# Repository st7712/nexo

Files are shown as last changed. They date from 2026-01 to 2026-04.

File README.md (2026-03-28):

<div align="center">
  Nexo Logo
  <h1>Nexo Smart Speaker</h1>
  
  <p>
    <strong>A DIY, open-source smart speaker built on Raspberry Pi.</strong>
  </p>

  <p>
    <a href="https://github.com/st7712/nexo?tab=readme-ov-file#features">Features</a> •
    <a href="https://github.com/st7712/nexo?tab=readme-ov-file#installation">Installation</a> •
    <a href="https://github.com/st7712/nexo?tab=readme-ov-file#hardware">Hardware</a> •
    <a href="https://github.com/st7712/nexo?tab=readme-ov-file#configuration">Configuration</a> •
    <a href="https://discord.com/users/stitoo">Support</a>
  </p>

  
  
  
</div>

---

## About
**Nexo** converts a standard Raspberry Pi into a high-fidelity, network-aware smart speaker. Unlike standard Bluetooth speakers, Nexo acts as a central audio hub that intelligently manages input sources.

It runs a headless Python controller that seamlessly switches between **Spotify Connect** (High Quality WiFi streaming) and **Bluetooth** (for guests/offline use). It also features professional-grade DSP (Digital Signal Processing) via **Carla**, allowing for active crossover tuning, EQ, and room correction directly on the device.

<div align="center">
  Nexo speaker
</div>

## Features

- **Priority Audio Switching**: Automatically switches inputs. Playing Spotify pauses Bluetooth; stopping Spotify wakes Bluetooth back up.
- **Smart Connectivity**:
  - **Spotify Connect**: Stream directly from the cloud.
  - **Bluetooth 5.0**: High-quality A2DP sink with intelligent pairing.
- **Hardware Control**: Sonos-inspired play/pause/skip middle button, with side volume buttons, and status LEDs.
- **Pro-Audio Engine**: Uses [PipeWire](https://pipewire.org/) & [Carla](https://kx.studio/Applications:Carla) for low-latency audio processing and equalization.
- **API Controlled**: Built-in FastAPI backend for mobile app integration and smart home control.
- **Persistent Settings**: Remembers volume and EQ profiles across reboots.
- **Pretty good frequency response**: The exact speaker with the listed parts has a decent frequency response:
nexo curve
> Measured with an uncalibrated microphone with poor high frequency coverage and at 40 % speaker total volume.

## Installation

**Prerequisites:**
* Raspberry Pi 3B+, 4 or 5 (Recommended)
* Raspberry Pi OS (Bookworm or newer)

**Installer:**
SSH into your Raspberry Pi and run this command. It will install dependencies, compile Spotifyd, and configure system services automatically.

```bash
sudo apt update && sudo apt install -y git && \
git clone https://github.com/st7712/nexo.git && \
cd nexo && chmod +x install.sh && sudo ./install.sh
```

*Note: The installation may take 10-20 minutes depending on your Pi model (compiling Rust dependencies takes time).*

## Usage

### Physical Controls

| Button Input | Action |
| --- | --- |
| **Vol + / -** (Click for 5% / Hold for 10% continuous) | Changes Volume (Synchronized with Spotify/Bluetooth) |
| **Play (1 Click)** | Play / Pause |
| **Play (2 Clicks)** | Next Track |
| **Play (3 Clicks)** | Previous Track |
| **Play (Hold)** | **Force Pairing Mode / Restarts Spotify** (Disconnects current user from Bluetooth if Bluetooth active and also restarts Spotifyd) |

### API / App

The speaker hosts a local API at `http://<raspberry-pi-ip>:8000`. You can control playback, volume, EQ, and fetch metadata via REST.

## Hardware

Nexo is designed to work with generic I2S DACs (like HiFiBerry, Pimoroni, or generic PCM5102).

- **[View my Full Hardware Docs](https://github.com/st7712/nexo/blob/main/hardware/README.md)** 
- **[View my Bill of Materials (BOM)](https://github.com/st7712/nexo/blob/main/hardware/bom.md)**
- **[View my Full Hardware Assembly Guide](https://github.com/st7712/nexo/blob/main/hardware/assembly_guide.md)** 

## Configuration

Advanced users can tweak GPIO pins and audio settings.

1. **System Config**: Edit `assets/configs/nexo_config.json` (created after first run) or `DEFAULT_CONFIG ` in `src/data_handler.py` directly.
* Change `device_name` to whatever name you'd like
* Set `sounds` whether or not you want to have sound effects
* Modify `eq_presets` to change the equalizer presets to your liking
* Edit `max_volume` to match your specific amplifier
* ~Switch `master` if you'd like to have the specific speaker as just a listener, not a broadcaster~ (multi-room is in development)

2. **Pin Layout**: Edit `src/led_helper.py` if you use different GPIO pins for LEDs and `src/main.py` for buttons.
3. **Specific Carla settings**: Edit `src/carla_osc.py` if you somehow changed the Carla config and are using different plugins.

## Contributing

Contributions are welcome! Please open an issue or submit a pull request.

1. Fork the repo.
2. Create your feature branch (`git checkout -b feature/AmazingFeature`).
3. Commit your changes.
4. Push to the branch.
5. Open a Pull Request.

## Used Projects

* [Spotifyd](https://github.com/Spotifyd/spotifyd) - Lightweight Spotify Client
* [Carla](https://kx.studio/Applications:Carla) - Audio Plugin Host
* [FastAPI](https://fastapi.tiangolo.com/) - Modern Python Web Framework
* [Linux Studio Plugins](https://lsp-plug.in/) - VST Plugins Used In Carla

## Feedback

Created by **@stitoo**. Reach out on Discord or open a GitHub Issue!

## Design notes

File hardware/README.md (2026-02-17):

# Nexo Hardware Overview

This directory contains all the documentation regarding the physical construction, wiring, and component selection for the Nexo Smart Speaker.

Unlike standard 3D-printed speakers, Nexo aims for high-density acoustic properties by combining 3D printing, wood, and composite materials.

## Documentation

- **[Bill of Materials (BOM)](https://github.com/st7712/nexo/blob/main/hardware/bom.md)** - Full parts list, costs, and purchase links.
- **[Assembly Guide](https://github.com/st7712/nexo/blob/main/hardware/assembly_guide.md)** - Step-by-step tutorial on building the enclosure and wiring.

---

## Design Philosophy & Component Selection

### 1. The Subwoofer Enclosure (Plaster + PVA)

One of the biggest issues with DIY 3D printed speakers is that plastic is light and resonates easily, which makes the bass muddy.

- The subwoofer enclosure walls are designed with hollow cavities.
- I filled these cavities with a mixture of **Plaster of Paris**. Plaster of Paris and water is mixed using a 1:1 ratio, the **PVA glue** is then mixed with about an 1:10 ratio with the Plaster of Paris. I recommend trying out exact ratios yourself though.
- The PVA makes the plaster less brittle and significantly denser. This creates a "dead" cabinet that doesn't vibrate, resulting in much cleaner low-end frequencies.

### 2. The Amplifier (TPA3255)

I originally looked at standard TPA3116D2 boards, but settled on the **TPA3255 (SAMP-100)**.

- It has significantly cleaner power delivery, has **zero "thump" noise** when powering on or off. It also is very powerful and should handle pretty much anything. Lastly it was actually pretty cheap because I was purchasing it used.

### 3. The Brain (Raspberry Pi 5)

I used a Raspberry Pi 5 (4GB).

- **It's very overkill.** A Pi 3B+ or 4 would work fine. Any basic RPi that can run Linux will work.
- I wanted to get a powerful RPi that I will be able to use for my other personal usecases too, as well as future learning with microcontrollers. Another reason was the fact that the Pi 4 wasn't much cheaper than the 5, so I went for it.

---

## Challenges & Problems Encountered

### Ground loops

Originally, I planned to power everything from the single 36V Mean Well power supply, using a cheap DC-DC buck converter to step down 36V -> 5V for the Raspberry Pi.

This created a massive ground loop. The shared ground between the Amp and the Pi (via the buck converter) introduced audible whining and screeching noise into the audio signal. The music playback was unusable and you couldn't hear anything other than the loud screech.

I removed the buck converter entirely. The final build uses:

1.  **Mean Well 36V PSU** -> Powering ONLY the Amplifier.
2.  **Official Raspberry Pi PSU** -> Powering the Raspberry Pi.
    _This isolates the power grounds and results in a completely silent noise floor._

This also brings a benefit of being able to have the RPi running 24/7 without any coil whine, because the RPi PSU is silent.
However it does add another cable that goes to the speaker, which might make it look clunky.

If you prefer a single cable installation, I recommend getting either an isolated DC-DC converter, or an RCA (or AUX) ground loop isolator, which will effectively remove the ground loop, however the isolated DC-DC converter is expensive, and the RCA isolator might reduce audio quality.

Another internal PSU (like the RPi PSU) can be also actually placed inside of the enclosure and be wired up to the C14 connector, effectively using just one cable, however that would require more inside space, which I couldn't afford.

### Not ideal CAD design

There were a few issues when assembling the enclosure together.
The main issue was the lack of heat inserts or at least somewhat inserted screw nuts in the design, later requiring the manufacturing of special screw rings, that properly hold the speakers.

---

## 🖼️ Gallery

<div align="center">
  wiring diagram
  parts
</div>

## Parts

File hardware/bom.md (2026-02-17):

# Bill of Materials (BOM)

This is the list of parts used to build the reference version of the Nexo Speaker. Prices are estimates and may vary by region.

### Electronics

| Item | Description | Qty | Est. Cost | Notes | Link |
| :--- | :--- | :-- | :--- | :--- | --- |
| **Raspberry Pi 5 (4GB)** | The brain. Pi 4 also works. | 1 | $80 - $90 | Needs WiFi capability. I specifically chose this one as I'll use it for other projects too in the future. Such a powerful Pi isn't needed. | [Raspberry Pi](https://www.raspberrypi.com/products/raspberry-pi-5/) |
| **Raspberry Pi DAC+** | High-quality audio output board. | 1 | $25 | Any DAC will most likely work great. | [Raspberry Pi](https://www.raspberrypi.com/products/dac-plus/) |
| **Amplifier Board (TPA3255 SAMP-100)**  | Class D Amp, 2x315W. | 1 | $16 | Ensure it fits your power needs for your speakers. I specifically chose this one because it was for a good price and also because these TPA3255 boards do not have the thump noise when powering on/off that TPA3166D2 boards do have. | [Aliexpress](https://www.aliexpress.com/item/1005006169802448.html) |
| **Power Supply (Mean Well LRS-150-36)** | An industrial power supply | 1 | $24 | Powers the Amp and Raspberry Pi. You can choose any PSU you need, even an external one, I would personally not choose this exact one because of coil whine and tons of electrical noise going into the amp, however it's good enough. | Any official Mean Well store. |
| ~**DC-DC Buck Converter**~ | ~Steps down 36V -> 5V for the Pi.~ | ~1~ | ~$3~ | ~Choose one specifically for your Pi, I wanted a 5A one, because the Pi 5 wants 5A to be happy. This one delivers that and shouldn't fry the Pi.~ This was NOT used in the final version as it introduced a ground loop. I decided to get a secondary official Raspberry Pi PSU for the Pi 5. This does add another cable, but allows the Pi to run 24/7 with no noise. | ~[Aliexpress](https://www.aliexpress.com/item/1005009039465768.html)~ [Raspberry Pi](https://www.raspberrypi.com/products/27w-power-supply/) |
| **Buttons** | For Vol +/-, Play/Pause. | 3 | $1 each | I specifically chose ones that can sense a finger from a few milimeters away, because they'll be under the surface in the enclosure. | [Aliexpress](https://www.aliexpress.com/item/1005004477188195.html) |
| **White LEDs** | Status feedback. | 1 | $2 for 50-pack | I chose white color for a minimalistic look. | [Aliexpress](https://www.aliexpress.com/item/1005006885163813.html) |
| **PANASONIC AQY212EHAT opto-coupler** | For controlled AMP muting. | 1 | $3 | Because my AMP supports hardware muting when two pins are shorted, I am using an opto-coupler to control the short with the RPi. | Any local electronics store |

### Audio Components

| Item | Description | Qty | Est. Cost | Notes | Link |
| :--- | :--- | :--- | :--- | :--- | --- |
| **Woofer (4 inch)** | Mid-bass driver. | 1 | $25 | I chose the Dayton Audio TCP115-4 4", good little woofer for a good price. | [Amazon](https://www.amazon.com/Dayton-Audio-TCP115-4-Treated-Midbass/dp/B077FHPGM4) |
| **Tweeter (2 inch)** | Silk dome tweeters. | 1 (set of 2) | $7 | These tweeters are pretty decent for the price. | [Aliexpress](https://www.aliexpress.com/item/1005007917972560.html) |
| **Mid speakers (3 inch)** | Mid frequency speakers. | 1 (set of 2) | $11 | These are not all that great, but they get the job done. | [Aliexpress](https://www.aliexpress.com/item/1005007256226541.html) |
| **High-pass filter** | For tweeters. | 1 | $4 | You don't need it if you're not using tweeters. | [Aliexpress](https://www.aliexpress.com/item/1005001361438676.html) |

### Enclosure & Misc

| Item | Description | Notes |
| :--- | :--- | :--- |
| **PETG Filament** | About 1 kg of filament used + wood. | PCTG _might_ be better. |
| **Wooden board** | For the outer enclosure. | Makes it look neat and saves plastic. |
| **Plaster of paris mixture with PVA** | Acoustic stuffing for the woofer enclosure. | A classic 1:1 PoP mixture with a bit of added PVA to make it less brittle. |
| **Screws / Binding Posts** | For rigid links. | An y nice looking screws, I chose black DIN 7984. |
| **Various cables** | For all connections. | You should choose a cable thick enough to handle the power. I chose 14 AWG cables for power and 1.5qmm cables for speakers. |

**Total Estimated Cost:** ~$200 - $250 USD

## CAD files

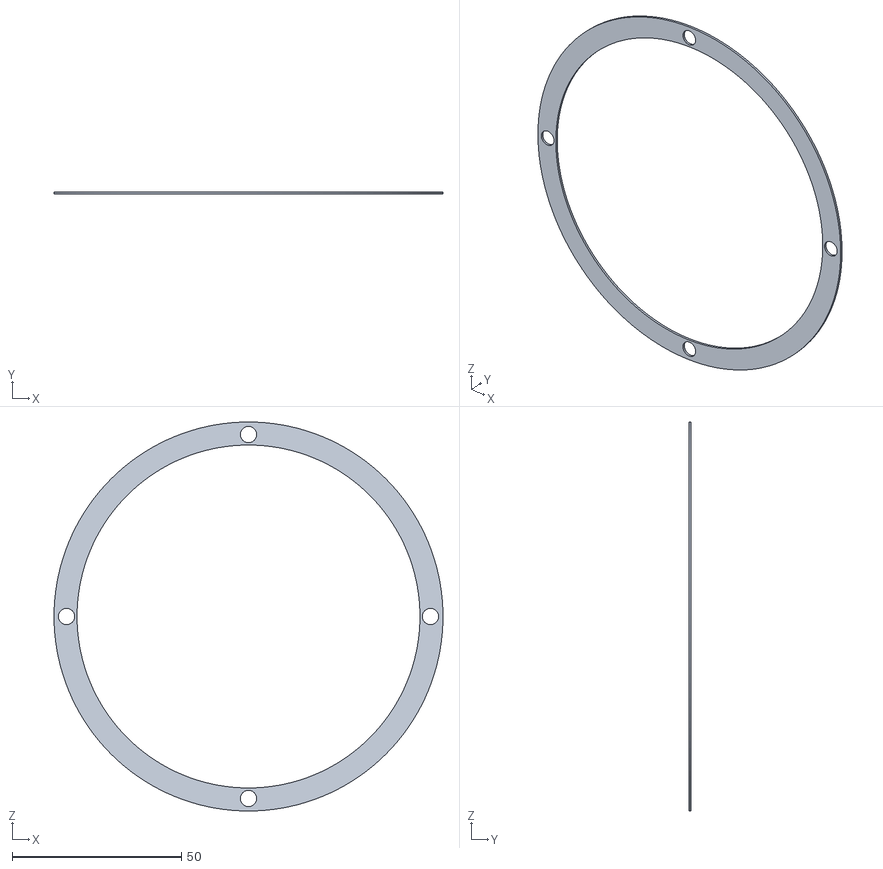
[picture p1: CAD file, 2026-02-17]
hardware/CAD/passive radiator rubber gasket.stl
114.8 x 0.7 x 114.8

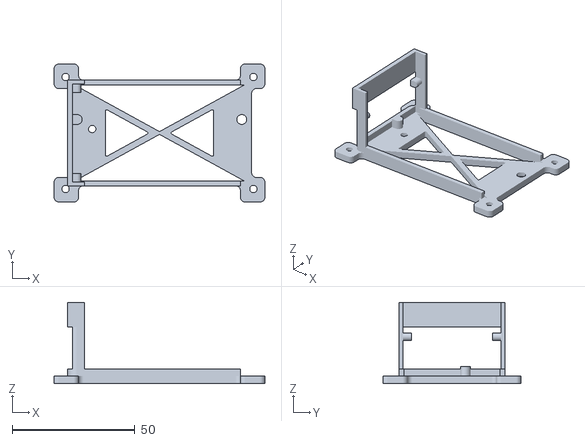
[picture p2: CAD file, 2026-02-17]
hardware/CAD/DC DC holder.stl
85.9 x 56.2 x 33.0

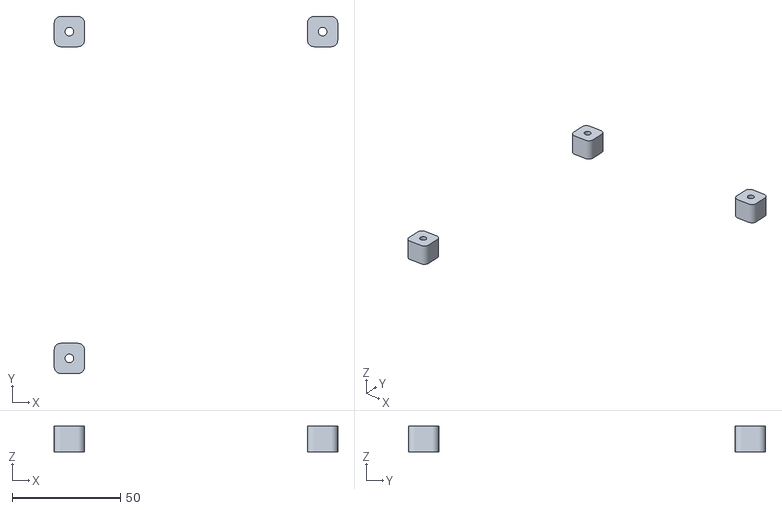
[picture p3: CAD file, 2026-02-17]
hardware/CAD/psu standoffs.stl
131.2 x 165.2 x 12.0

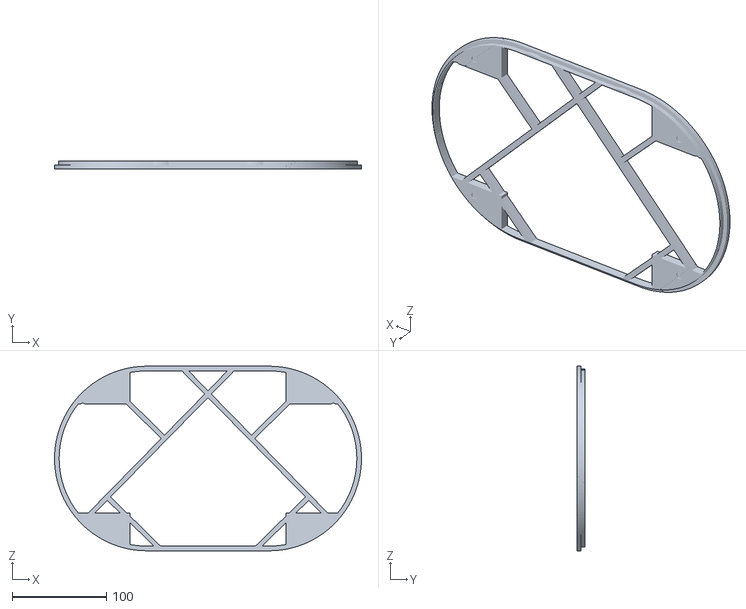
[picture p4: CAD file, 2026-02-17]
hardware/CAD/split front cover parts.stl
326.0 x 8.00 x 196.0

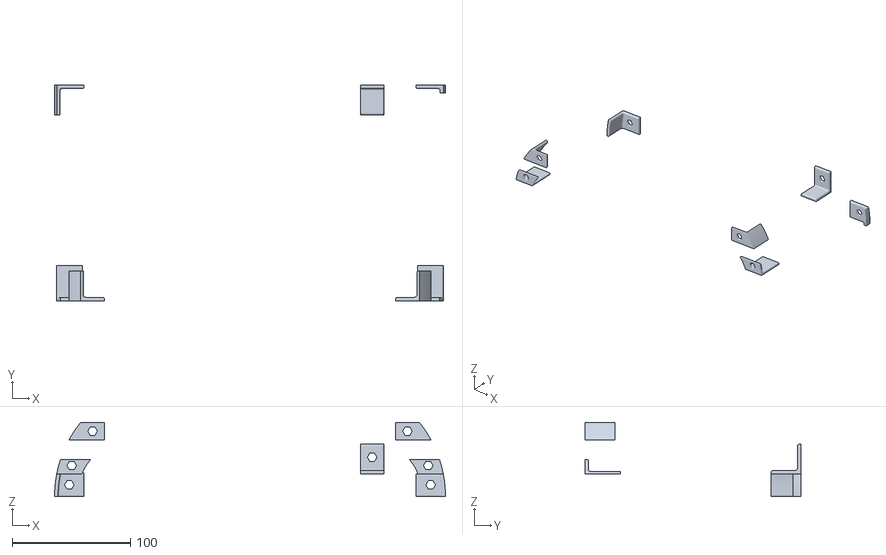
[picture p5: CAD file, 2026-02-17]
hardware/CAD/speaker enclosure holders.stl
330.0 x 182.0 x 62.8

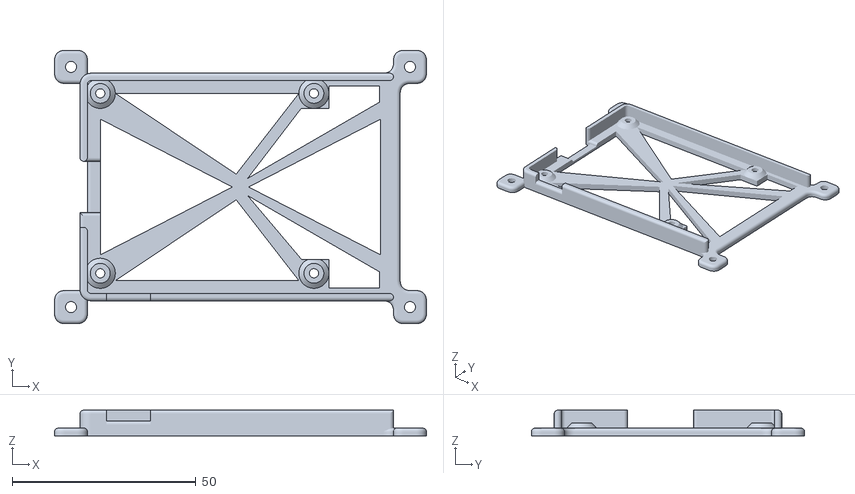
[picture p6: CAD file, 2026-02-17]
hardware/CAD/RPI5 holder.stl
101.3 x 74.4 x 7.00

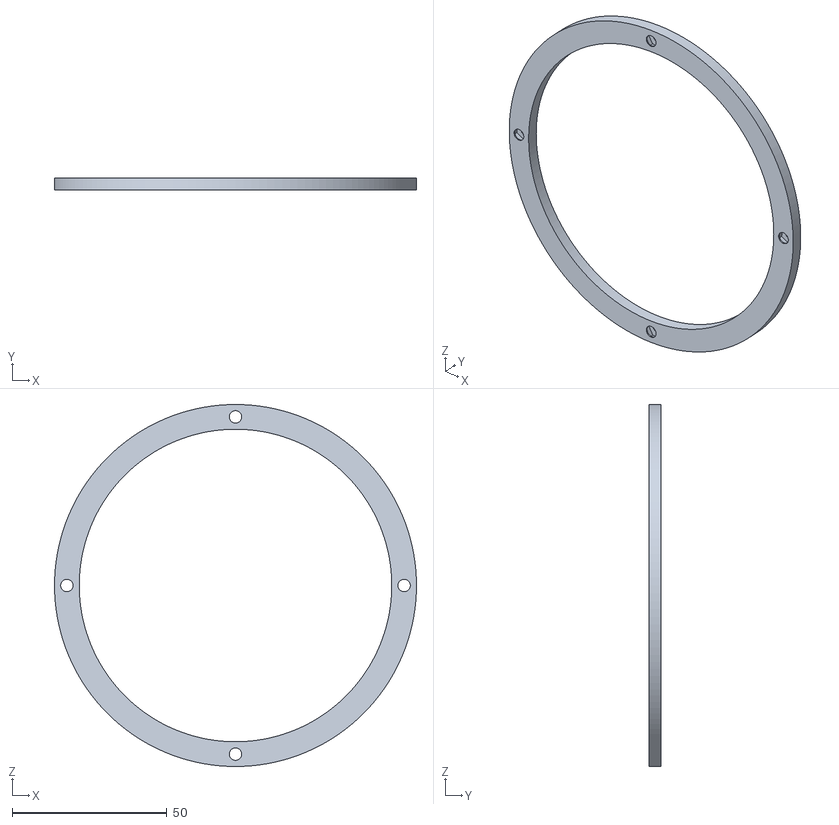
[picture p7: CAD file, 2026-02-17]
hardware/CAD/front speaker offset ring with nuts covered.stl
117.0 x 4.00 x 117.0

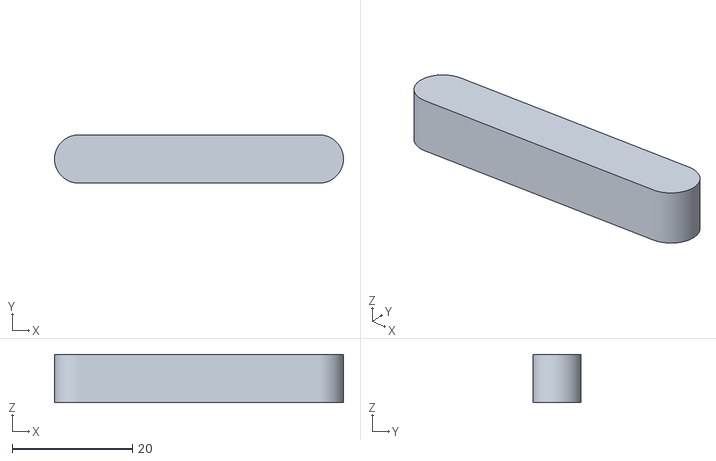
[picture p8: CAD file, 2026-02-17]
hardware/CAD/LED holder.stl
48.0 x 8.00 x 8.00

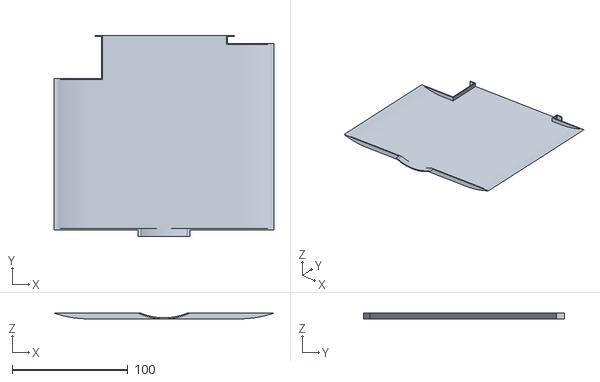
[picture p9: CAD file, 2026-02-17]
hardware/CAD/outside plaster enclosure top.stl
190.2 x 173.8 x 5.00

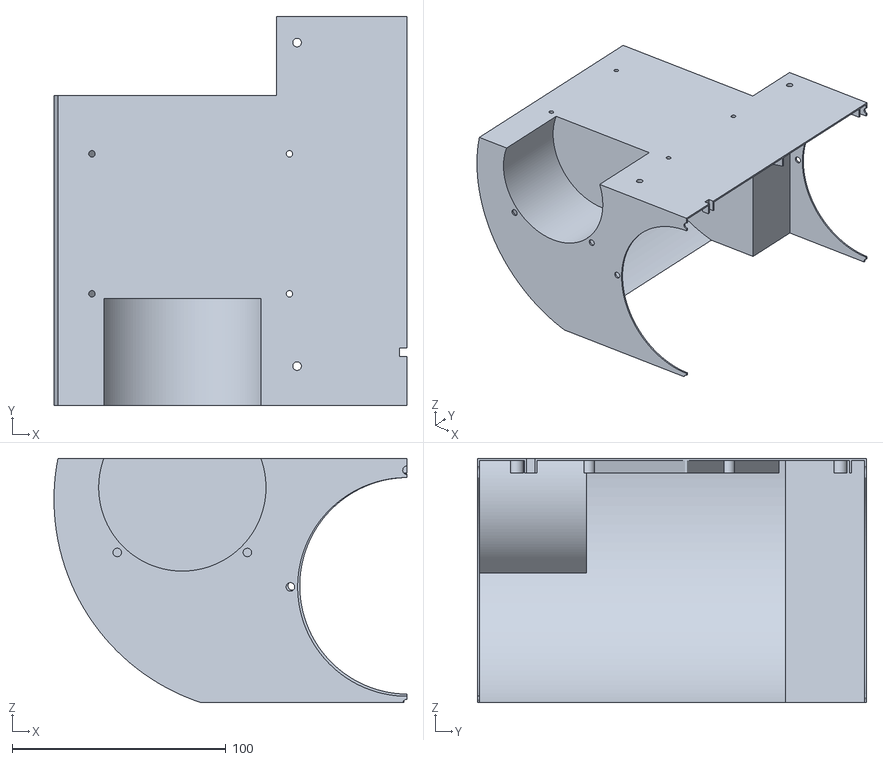
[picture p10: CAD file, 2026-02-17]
hardware/CAD/outside plaster enclosure 2.stl
165.0 x 182.0 x 114.2

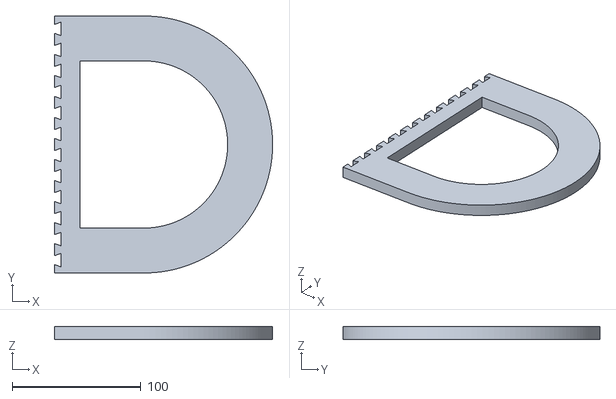
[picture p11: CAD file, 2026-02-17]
hardware/CAD/wood curve jig 2.stl
169.9 x 200.0 x 10.0

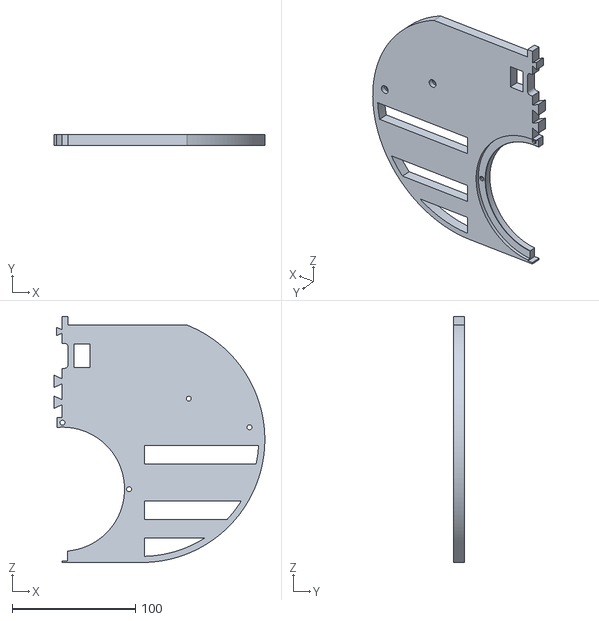
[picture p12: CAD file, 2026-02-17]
hardware/CAD/back plate 2.stl
171.3 x 9.00 x 200.0

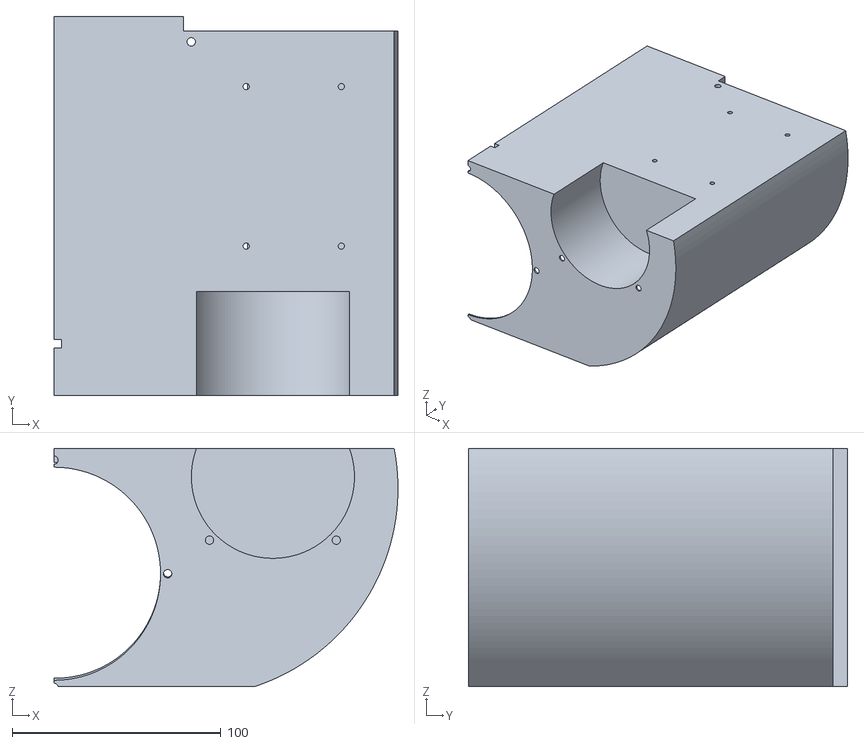
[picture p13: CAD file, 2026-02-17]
hardware/CAD/outside plaster enclosure 1.stl
165.0 x 182.0 x 114.2

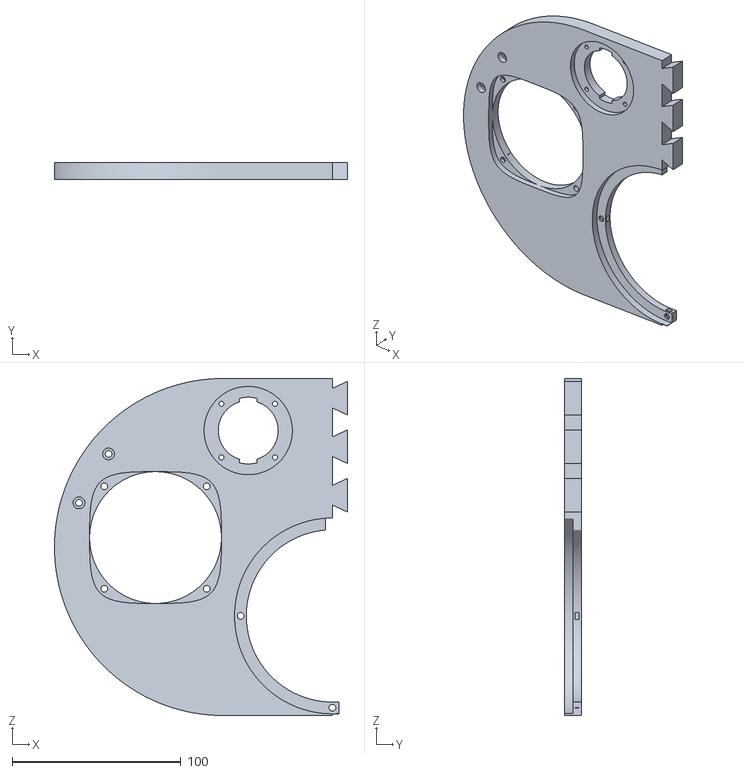
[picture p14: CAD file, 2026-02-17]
hardware/CAD/front plate 2.stl
174.0 x 10.0 x 200.0

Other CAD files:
hardware/CAD/PSU holder.stl
hardware/CAD/wood curve jig 1.stl
hardware/CAD/speaker bottom rubber v3.stl
hardware/CAD/inside plaster enclosure 1.stl
hardware/CAD/back plate 1.stl
hardware/CAD/front plate 1.stl
hardware/CAD/inside plaster enclosure 2.stl
hardware/CAD/inside plaster enclosure top.stl

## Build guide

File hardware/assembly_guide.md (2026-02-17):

# Nexo Assembly Guide

This guide details the process of printing, building, and wiring the Nexo Smart Speaker.

## Safety Warning

- **Mains Voltage:** This project uses an industrial power supply (110V/220V).
- **Chemicals:** When mixing Plaster and PVA, wear gloves and work in a ventilated area.
- **Wood working:** When cutting/sanding/milling the wooden parts, wear safety glasses and watch out for your hands.

---

## Phase 1: The Enclosure

### 1. 3D Printing

All parts were printed in **PETG** for durability and heat resistance.

- **Walls:** 2 perimeters (minimum).
- **Infill:** 15% Rectilinear (except for the subwoofer walls which are hollow for filling).

All printing parameters should be set to your specific printer. I personally printed everything on more filament and time saving settings and everything turned out great, so as long as you know which settings get you a decent quality print, I wouldn't be too worried about settings.

> **Note on Material:** PETG is completely fine to use, however using PCTG might be beneficial because of the higher temperature resistance (though in tests, it looks like it's not much different from PETG).

### 2. The Composite Fill (Subwoofer)

To give the subwoofer weight and acoustic density:

1.  Prepare a mixture of **90% Plaster of Paris** and **10% PVA Glue** (White wood glue).
2.  Add a small amount of water until it reaches a "pourable pancake batter" consistency if too viscous.
3.  Pour the mixture into the hollow cavities of the 3D-printed subwoofer shell.
4.  **Let it cure for at least 48 hours.** The PVA slows down the drying process but prevents the plaster from cracking. Also make sure it's in a well ventilated and/or heated area, so that it's not wet.
5.  Once it's all set, put some cotton wool (or polyfil) inside the enclosure, to help with bass response and make the enclosure feel "bigger" than it actually is.



### 3. Woodworking

The outer shell utilizes a wooden board for aesthetics and extra rigidity.

The wooden board uses a kerf bending method to bend the sides of the board according to the circular edges of the speaker enclosure. Make sure to cut the kerf cuts accordingly.

- Cut the board to size according to the following template including the kerf cuts.
- Use a router (or a Forstner bit) to carve out spaces for the buttons and LEDs.
- Sand up to 400 grit and apply oil/stain before final assembly.
- Bend (and glue the kerf cuts) the upper half of the board so that it fits the upper half of the speaker, leave the bottom straight so the speaker can be easily wrapped around with the wood.
- Finally varnish and color (if wanted) the wood enclosure to fit your needs.

This part can definitely also be 3D printed out of PETG, which was initially planned anyways. I just thought wood might look better plus it saved like 600 grams of plastic.



### Other Tasks

- Put a silicon ring around the holes for the subwoofer speaker and passive radiator to get a good seal on the enclosure. Caulk can be used for this.
- Glue everything needed together. (Such as the parts of the subwoofer enclosure, mounting rings to the enclosure).
- Paint and/or polish the look of the front and back plates. You can use wood filler to make it look more matte and less like plastic.
- Screw components into their specific holders.
- place the C14 plug and switch into its holes on the back plate, wire everything up.
- Screw the amplifier onto the inner side of the back plate and connect everything up correctly to it (the right channel to the woofer, the left channel to all the other speakers), the tweeters should be conneted through the high pass filter.

---

## Phase 2: Electronics & Wiring

### 1. Wiring Diagram

Below is a _(very professional)_ connection map of the Raspberry Pi and small electronics:

wiring diagram

- The LEDs and buttons are connected to a common ground coming from the RPi (the buttons connections depend on your specific buttons, mine required 5V, GND and had a signal OUT).
- Each LED is independently connected to the specific used pins to the RPi, every LED also has a resistor before connecting to the ground.
- Each button signal output is also connected to the RPi so that we know when it was pressed.
- Finally, the optocoupler is connected to its own pin and ground which then is able to control the muting of the amplifier using just a simple LOW/HIGH signal from the RPi.

### 2. Power System

- **Amp Power:** Connect the Mean Well 36V PSU output to the TPA3255 amp input using **14 AWG** silicone wire.
- **RPi Power:** Run the official USB-C power supply to the Pi 5.
  > Or you can power the RPi using the internal psu using an isolated DC-DC converter or by then using a ground loop isolator on the audio output of the RPi.

### 3. The Mute Circuit

Since the SAMP-100 TPA3255 amp board supports hardware muting, I implemented an optocoupler circuit to let the Pi mute the amp to prevent unnecessary electrical noise when no music is playing.

- **Optocoupler:** Panasonic AQY212EHAT.
- **Connection:**
  - _Input Side:_ GPIO 26 (RPi) -> Resistor -> Optocoupler LED -> GND (RPi).
  - _Output Side:_ Connects the Amp's MUTE and GND pins, polarity on this specific optocoupler and amp doesn't matter.

---

## Phase 3: Final Assembly

1.  **Mounting Drivers:** Screw the woofer and tweeters into the front plate.
2.  **Mounting Electronics:** Screw the electronic components in their mounting holders onto the enclosure.
3.  **Closing the Box:** Screw the subwoofer speaker and passive radiator very tightly into the subwoofer enclosure to ensure an airtight seal.
4.  **Wrap the rest using the bendable wood:** Enclose the whole speaker in the wood. Make sure the bottom part of the wooden board holds nicely, glue the bottom part down properly and let it sit for a while.

The whole speaker should be finished now.

---

## What I would do differently

Here are things I would change in a future build. You might want to consider these before you build yours:

### 1. Threaded Inserts

In this version, I screwed directly into the plastic and/or used nuts held in place by friction and super glue.

- Use **Heat-Set Inserts (M3/M4)** for every screw point. Redesign the 3D files to accommodate them.
- This will overall fix mounting issues and might help seal the subwoofer enclosure airtight a bit more.

### 2. Power Supply Integration

Having two power plugs (one for Amp, one for Pi) is clunky.

- Find an isolated DC-DC converter that actually works without ground loops, or build a custom linear power supply stage to feed 5V from the 36V rail cleanly.
  > Or just use a ground loop isolator at the RCA DAC connections (might hurt audio quality).

### 3. Ease of opening

Currently, removing the wooden is practically impossible, because it's glued down to the actual speaker enclosure.

- It would be a lot better to make some mounting plates sticking out of the wood to properly mount the back and front plates, so that it can be removed properly.
- Also placing all of the back plate mounted components onto the enclosure might help too, because the back plate would be removable a bit better, however it still has all the mains power on it, which is still a big issue.

> These are all quality of life improvements, that physically don't need to be there for it to work really good, but they could be good to have in the long term. For me though, they don't really cause issues for now.

---

## All .stl files for 3D printing are available in the `/files` directory.

- All CAD was designed in OnShape and the direct link to the CAD so you can clone it and edit parts directly is [**here**](https://cad.onshape.com/documents/64120ed53810ec4d5c769f33/w/fbffd58ca4d500f12472e03c/e/86b9a890bc291adbebea1ccb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)

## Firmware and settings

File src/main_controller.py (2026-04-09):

from threading import Timer, Thread
from time import sleep
import subprocess

import spotify_helper as spotify
import led_helper as leds
import bluetooth_helper as bluetooth
import system_helper as system
import data_handler
from carla_osc import set_loudness_contour_eq

# --- SHARED STATE ---
# This dictionary lives here. Anyone importing this file shares this state
# (as long as they run in the same process).
state = {
    'volume': data_handler.db.get("volume", 50),
    'max_volume': data_handler.db.get("max_volume", 50),
    'current_mode': 'spotify', # 'spotify' or 'bluetooth'
    'bt_owner_mac': None,
    'click_count': 0,
    'click_timer': None,
    'down_held': False,
    'up_held': False,
    'active_btn': None,
}

LOUDNESS_SLOPES = {
    40: 0.00394,
    63: 0.00521,
    100: 0.00372,
}

CONNECT_SOUND_PATH = f"{data_handler.db.get('root_path')}/assets/sounds/connect.wav"

# volume functions
def sync_volume():
    """Syncs internal state with Spotify's actual volume."""
    state['volume'] = spotify.get_volume()
    print(f"Synced volume: {state['volume']}%")

def change_volume(amount, override=False):
    """
    Main volume function. Called by Buttons OR API.
    """
    old_volume = state['volume']
    
    # Update State
    if override:
        new_volume = max(0, min(100, amount))
    else:
        new_volume = max(0, min(100, state['volume'] + amount))
        
    state['volume'] = new_volume
    
    if new_volume > old_volume:
        # Drop EQ first to prevent clipping
        update_loudness_contour(new_volume)
        _apply_hardware_volume(new_volume)
    elif new_volume < old_volume:
        # Drop Amp volume first to prevent bass spikes
        _apply_hardware_volume(new_volume)
        sleep(2) # Short delay to let hardware catch up before adjusting EQ
        update_loudness_contour(new_volume)

    # Visual Feedback and save to DB
    leds.update_volume_display(state['volume'])
    data_handler.db.set("volume", state['volume'])

def _apply_hardware_volume(vol):
    """Helper function to apply volume changes to the correct output."""
    if state['current_mode'] == 'bluetooth':
        bluetooth.set_bluetooth_volume(vol)
        print(f"Vol (BT): {vol}")
    else:
        spotify.set_volume(vol)
        print(f"Vol (Spotify): {vol}")

def get_volume():
    sync_volume() # Ensure we have the latest volume before returning
    return state['volume']

# media control functions
def media_action(action):
    """
    Unified media control.
    action: 'play_pause', 'next', 'prev', 'kick_spotify', 'pairing_mode'
    """
    print(f"Controller: Executing {action}")
    
    if action == 'play_pause':
        spotify.play_pause()
        leds.ramp_main_led(0.1)
        update_mute_status() # Check immediately
        
    elif action == 'next':
        spotify.next_track()
        leds.ramp_main_led(0.1)
        sleep(0.1)
        leds.ramp_main_led(0.1)
        
    elif action == 'prev':
        spotify.previous_track()
        leds.ramp_main_led(0.1)
        sleep(0.1)
        leds.ramp_main_led(0.1)
        sleep(0.1)
        leds.ramp_main_led(0.1)

    elif action == 'kick_spotify':
        # Force Restart Spotifyd
        leds.ramp_main_led(0.1)
        sleep(0.1)
        leds.ramp_main_led(0.1)
        system.restart_spotifyd()
        
    elif action == 'pairing_mode':
        # Force Bluetooth Pairing
        leds.ramp_main_led(1.0) # Long flash
        state['bt_owner_mac'] = None
        system.enter_pairing_mode()
        # Flash to indicate searching
        for _ in range(5):
            leds.ramp_main_led(0.1)
            sleep(0.1)

# background workers
def update_mute_status(status=None):
    """Checks if we should mute the Amp."""
    print(f"Updating Amp Mute Status...{status}")
    try:
        if status is None:
            status = subprocess.check_output(["playerctl", "status"], text=True).strip()
        if status == "Playing":
            leds.set_amp_mute(False)
        else:
            leds.set_amp_mute(True)
    except:
        leds.set_amp_mute(True)

global status

def background_worker_loop():
    """
    The main brain loop. Checks priority, muting, and bluetooth security.
    """
    hardware_sink = system.find_hardware_sink()
    
    while True:
        # Check Spotify Status
        spotify_active, status = system.is_spotify_active()
        
        if (not status):
            status = "unknown"
        
        # Handle Amp Mute
        # To save another request to the terminal, we pass the status we already have
        update_mute_status(status)
        
        # If paused, start a timer to kick after 5 minutes
        if spotify_active and status == "Paused" and 'spotify_disconnect_timer' not in globals():
            print("Spotify is paused. Starting disconnect timer.")
            
            global spotify_disconnect_timer
            
            spotify_disconnect_timer = Timer(300, media_action, args=('kick_spotify',))
            
            spotify_disconnect_timer.start()
        elif status != "Paused" and 'spotify_disconnect_timer' in globals():
            # Cancel any existing timer
            try:
                print("Cancelling disconnect timer.")
                spotify_disconnect_timer.cancel()
                del spotify_disconnect_timer
            except Exception:
                pass

        # Priority Switching
        # Spotify just started playing -> Kill BT
        if spotify_active and state['current_mode'] == 'bluetooth':
            print(">>> Priority: Spotify took over.")
            system.turn_off_bluetooth()
            state['current_mode'] = 'spotify'
            system.play_sound(CONNECT_SOUND_PATH, volume=(get_volume() * 300))  # Scale 0-100 to 0-65536
            leds.ramp_main_led(1.0) # Feedback

        # Spotify stopped -> Restore BT
        elif not spotify_active and state['current_mode'] == 'spotify':
            print(">>> Priority: Spotify gone. Restoring BT.")
            system.turn_on_bluetooth()
            state['current_mode'] = 'bluetooth'
            state['bt_owner_mac'] = None # Open for connections
            leds.ramp_main_led(1.0) # Feedback

        # Bluetooth Security
        if state['current_mode'] == 'bluetooth':
            _bluetooth_bouncer()

        system.set_hardware_volume(state['max_volume'], forced_sink=hardware_sink)

        sleep(2)

def _bluetooth_bouncer():
    """Ensures only 1 person connects and trusts them."""
    try:
        connected = bluetooth.get_connected_devices()

        # New Connection -> Lock it
        if state['bt_owner_mac'] is None and len(connected) > 0:
            state['bt_owner_mac'] = connected[0]
            print(f"BT Locked to: {state['bt_owner_mac']}")

            # Make invisible so nobody else tries to pair
            subprocess.run(["bluetoothctl", "discoverable", "off"], check=False)
            subprocess.run(["bluetoothctl", "pairable", "off"], check=False)

        # Owner Left -> Unlock
        elif state['bt_owner_mac'] and state['bt_owner_mac'] not in connected:
            state['bt_owner_mac'] = None
            print("BT Unlocked.")
            
            # Re-open the doors for anyone
            subprocess.run(["bluetoothctl", "discoverable", "on"], check=False)
            subprocess.run(["bluetoothctl", "pairable", "on"], check=False)

        # Intruder -> Kick
        if len(connected) > 1:
            print(f"Too many devices! Enforcing limit...")
            for mac in connected:
                if mac != state['bt_owner_mac']:
                    bluetooth.disconnect_device(mac)
                    
    except Exception as e:
        print(f"Enforcer Error: {e}")

def volume_worker_loop():
    """Polls playerctl at 10Hz to catch external volume changes instantly."""
    
    last_known_volume = get_volume()
    
    while True:
        try:
            result = subprocess.run(
                ["playerctl", "volume"], 
                capture_output=True, 
                text=True, 
                timeout=0.2
            )
            if result.returncode == 0 and result.stdout.strip():
                external_vol_float = float(result.stdout.strip())
                current_vol = int(external_vol_float * 100)
                
                if current_vol != last_known_volume:
                    state['volume'] = current_vol
                    update_loudness_contour(current_vol)
                    
                    leds.update_volume_display(current_vol)
                    data_handler.db.set("volume", current_vol)
                    
                    last_known_volume = current_vol
                    
        except subprocess.TimeoutExpired:
            pass # DBus was busy, just try again next loop
        except ValueError:
            pass # playerctl returned something weird (not a number)
        except Exception as e:
            # playerctl might return an error if no players are active. Just ignore.
            pass
            
        sleep(0.1)

def start_workers():
    t = Thread(target=background_worker_loop, daemon=True)
    t.start()
    
    v = Thread(target=volume_worker_loop, daemon=True)
    v.start()

def get_full_system_state():
    """
    Compiles the complete state of the speaker for the App.
    """
    sync_volume()  # Ensure volume is up to date
    # Get Playback Data
    if state['current_mode'] == 'spotify':
        track_data = spotify.get_track_info()
    else:
        track_data = system.get_track_info_bluetooth()

    # Combine with System State
    full_state = {
        "volume": get_volume(),
        "mode": state['current_mode'],
        "track": track_data,
    }

    return full_state

def get_partial_system_state():
    """
    Returns a minimal state for quick checks.
    """
    sync_volume()  # Ensure volume is up to date
    partial_state = {
        "volume": get_volume(),
        "status": system.is_spotify_active()[1],
        "position": spotify.get_track_position(),
    }
    return partial_state

# system functions

def scan_wifi_networks():
    """Scans for available WiFi networks and returns a list of SSIDs."""
    networks = system.scan_wifi_networks()
    return networks

def connect_to_wifi(ssid, password):
    """Connects to a specified WiFi network."""
    system.connect_to_wifi(ssid, password)
    
def pairing_mode():
    """Enters speaker pairing mode."""
    system.create_temp_hotspot()
    
def update_loudness_contour(current_volume):
    """Updates the Loudness Contour EQ settings."""
    vol_drop = 80 - current_volume # Calculate how much the volume is reduced from max
    
    eq_settings = {}
    
    for freq, slope in LOUDNESS_SLOPES.items():
        osc_val = 0.5 + (slope * vol_drop) # Start at 0.5 (flat) and adjust based on volume drop
        osc_val = max(0.5, min(1.0, osc_val)) # Clamp between 0.5 and 1
        eq_settings[int(freq)] = round(osc_val, 3) # Round for cleaner OSC messages
        
    set_loudness_contour_eq(eq_settings)
    
    print(f"Loudness Contour Updated: {eq_settings}")

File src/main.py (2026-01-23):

from gpiozero import Button
from signal import pause
from time import sleep
from threading import Timer, Thread
import uvicorn

import main_controller as controller
import led_helper as leds
import startup
from data_handler import db
from api import app

# Pins
BTN_VOL_DOWN = 13
BTN_PLAY = 6
BTN_VOL_UP = 5

# Settings
HOLD_TIME = 0.6 # Faster hold response
BOUNCE_TIME = 0.05
MULTI_CLICK_SPEED = 0.4 
RAMP_SPEED = 0.1

# Buttons
btn_down = Button(BTN_VOL_DOWN, pull_up=False, hold_time=HOLD_TIME, bounce_time=BOUNCE_TIME)
btn_play = Button(BTN_PLAY, pull_up=False, hold_time=2.0, bounce_time=BOUNCE_TIME)
btn_up = Button(BTN_VOL_UP, pull_up=False, hold_time=HOLD_TIME, bounce_time=BOUNCE_TIME)

# Button handlers

# Volume
def on_vol_held(direction):
    """
    direction: 1 (Up) or -1 (Down)
    """
    button_name = "UP" if direction > 0 else "DOWN"
    print(f"Holding {button_name}")
    
    # Identify which button object to check
    btn_obj = btn_up if direction > 0 else btn_down
    
    controller.state['active_btn'] = button_name
    
    if direction > 0:
        controller.state['up_held'] = True
    else:
        controller.state['down_held'] = True
    
    if controller.state['active_btn'] != button_name:
        return # Another button took over

    controller.sync_volume()
    
    # Loop while user holds the button
    while btn_obj.is_pressed:
        if controller.state['active_btn'] != button_name:
            return # Another button took over
        controller.change_volume(5 * direction) # Change by +/- 5
        leds.ramp_main_led() # Tiny blink for feedback
        sleep(RAMP_SPEED)

def on_vol_press(direction):
    button_name = "UP" if direction > 0 else "DOWN"
    
    controller.state['active_btn'] = button_name
    
    if direction > 0 and controller.state['up_held']:
        controller.state['up_held'] = False
        return # Ignore, was part of hold
    elif direction < 0 and controller.state['down_held']:
        controller.state['down_held'] = False
        return # Ignore, was part of hold
    
    if controller.state['active_btn'] != button_name:
        return # Another button took over
    
    print(f"Tap {button_name}")
    controller.sync_volume()
    controller.change_volume(5 * direction)
    leds.ramp_main_led() # Tiny blink for feedback

# Play button
def execute_play_logic():
    count = controller.state['click_count']
    controller.state['click_count'] = 0 # Reset
    
    if count == 1:
        controller.media_action('play_pause')
    elif count == 2:
        controller.media_action('next')
    elif count >= 3:
        controller.media_action('prev')

def on_play_press():
    # Cancel previous timer
    if controller.state['click_timer']:
        controller.state['click_timer'].cancel()
    
    controller.state['click_count'] += 1
    
    # Start new timer
    t = Timer(MULTI_CLICK_SPEED, execute_play_logic)
    controller.state['click_timer'] = t
    t.start()

def on_play_hold():
    # Long press determines action based on current mode
    if controller.state['current_mode'] == 'spotify':
        controller.media_action('kick_spotify')
    else:
        controller.media_action('pairing_mode')
        sleep(0.5)
        controller.media_action('kick_spotify')

# Bindings

def start_api_server():
    # We run uvicorn programmatically.
    uvicorn.run(app, host="0.0.0.0", port=8000, log_level="warning")

# Volume Up
btn_up.when_released = lambda: on_vol_press(1)
btn_up.when_held = lambda: on_vol_held(1)

# Volume Down
btn_down.when_released = lambda: on_vol_press(-1)
btn_down.when_held = lambda: on_vol_held(-1)

# Play
btn_play.when_pressed = on_play_press
btn_play.when_held = on_play_hold

# Startup Sequence
sleep(3) # Wait for system to settle
print("--- BOOTING NEXO SPEAKER ---")
leds.set_amp_mute(True) # Mute Amp during startup
print(db.get("volume"))

print("--- DEBUG CONFIG ---")
print(db.get_all())
# Run System Startup (Carla, Spotifyd)
startup.start_up(db.get("volume", 50), db.get("max_volume", 50))

# Sync Initial Volume
controller.sync_volume()

# Start Background Workers (Priority, Mute, Bluetooth)
controller.start_workers()

# Start API Server Thread
# We start this in a daemon thread so it runs in the background
api_thread = Thread(target=start_api_server, daemon=True)
api_thread.start()
print("--- API SERVER STARTED (Port 8000) ---")

print("--- SYSTEM READY ---")

if db.get("wifi")["ssid"] == "":
    print("No WiFi configured. Entering pairing mode.")
    controller.pairing_mode()

pause()

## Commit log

2026-01-16 made play_sound function have a dynamic volume based on current speaker volume
2026-01-16 edited data_handler to handle dynamic root path resolving for stability, added max_volume setting
    [data_handler.py]
2026-01-17 added default sink set to PulseAudio virtual cable device to startup sequence
2026-01-23 changed equalizer base values to a more calibrated curve for my speaker
2026-01-23 updated max_volume of my specific speaker to 55, made everything else resolve to 50.
    [data_handler.py, main.py, main_controller.py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]
2026-02-17 Update assembly guide with images
2026-02-17 added all stl 3D printing parts
    [DC DC holder (1).stl, LED holder.stl, PSU holder.stl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]
2026-02-17 Rename DC DC holder (1).stl to DC DC holder.stl
    [DC DC holder.stl]
2026-03-28 Renamed folder to CAD
    [DC DC holder.stl, LED holder.stl, PSU holder.stl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]
2026-04-09 added short delay in volume change and EQ update
    [main_controller.py]

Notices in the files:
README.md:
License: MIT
